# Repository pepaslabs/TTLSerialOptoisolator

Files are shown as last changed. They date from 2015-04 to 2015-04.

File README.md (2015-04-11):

# TTLSerialOptoisolator

A board which provides isolation for a TTL serial TX / RX pair.

## License

This board design is [Open-Source Hardware](http://www.oshwa.org/definition/).  It is licensed under the [MIT License](http://opensource.org/licenses/MIT).  It was designed by Jason Pepas.

# Board design v1

Initial board design.

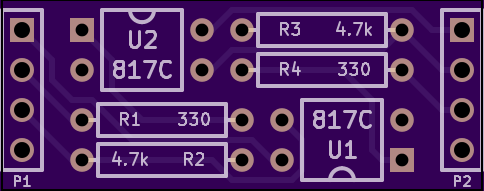
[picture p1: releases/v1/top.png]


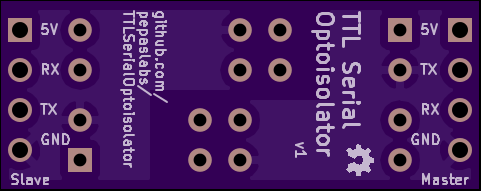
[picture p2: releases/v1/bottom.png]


## Gerbers

[gerbers.zip](releases/v1/gerbers.zip)

## Schematic

[PDF](releases/v1/TTLSerialOptoisolator%20schematic.pdf).

# Design notes

## LED series resistor calculation

Can we find an LED resistor value which works for both 3.3V and 5V TTL levels?

Lite-On LTV-817 datasheet: http://media.digikey.com/pdf/Data%20Sheets/Lite-On%20PDFs/LTV-817_827_847%28M,S,S_TA1%29.pdf

The forward voltage of the LED is typically 1.2V.

* 5V - 1.2V = 3.8V
* 3.3V - 1.2V = 2.1V

Voltage|100Ω|150Ω|220Ω|330Ω|470Ω|680Ω|1kΩ
-------|----|----|----|----|----|----|---
5V|38mA|25mA|17mA|12mA|8mA|6mA|4mA
3.3V|21mA|14mA|10mA|6mA|4mA|3mA|2mA

So 330Ω would be a reasonable choice.

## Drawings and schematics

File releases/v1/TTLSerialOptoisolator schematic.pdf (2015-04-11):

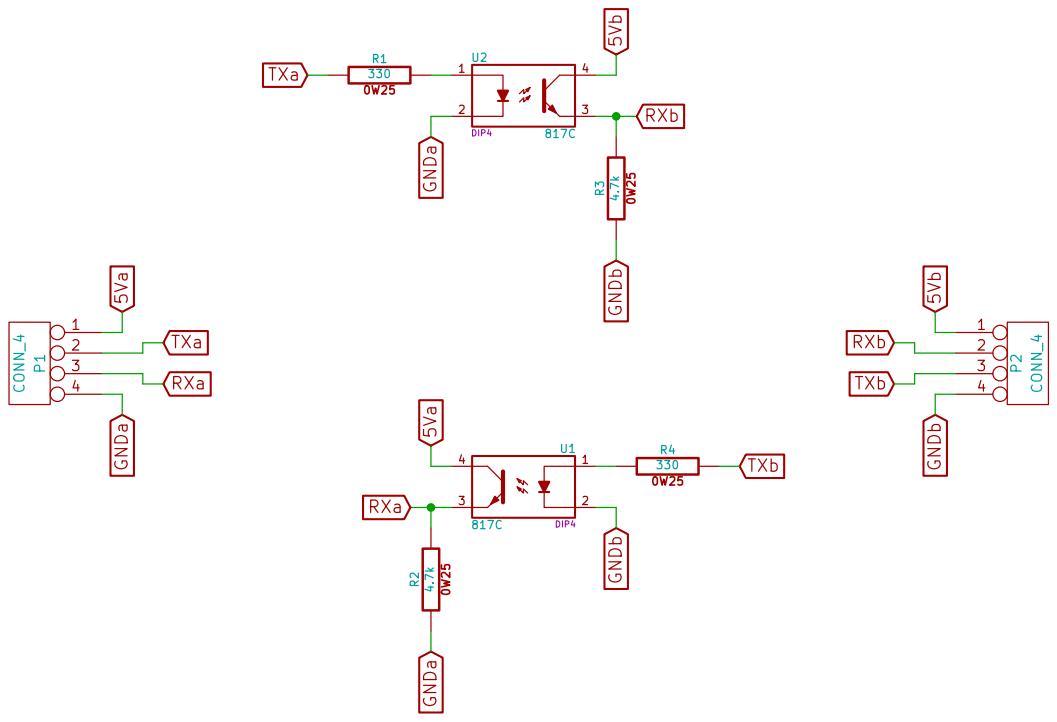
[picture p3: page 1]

Id: 1/1 Title: File: TTLSerialOptoisolator.sch

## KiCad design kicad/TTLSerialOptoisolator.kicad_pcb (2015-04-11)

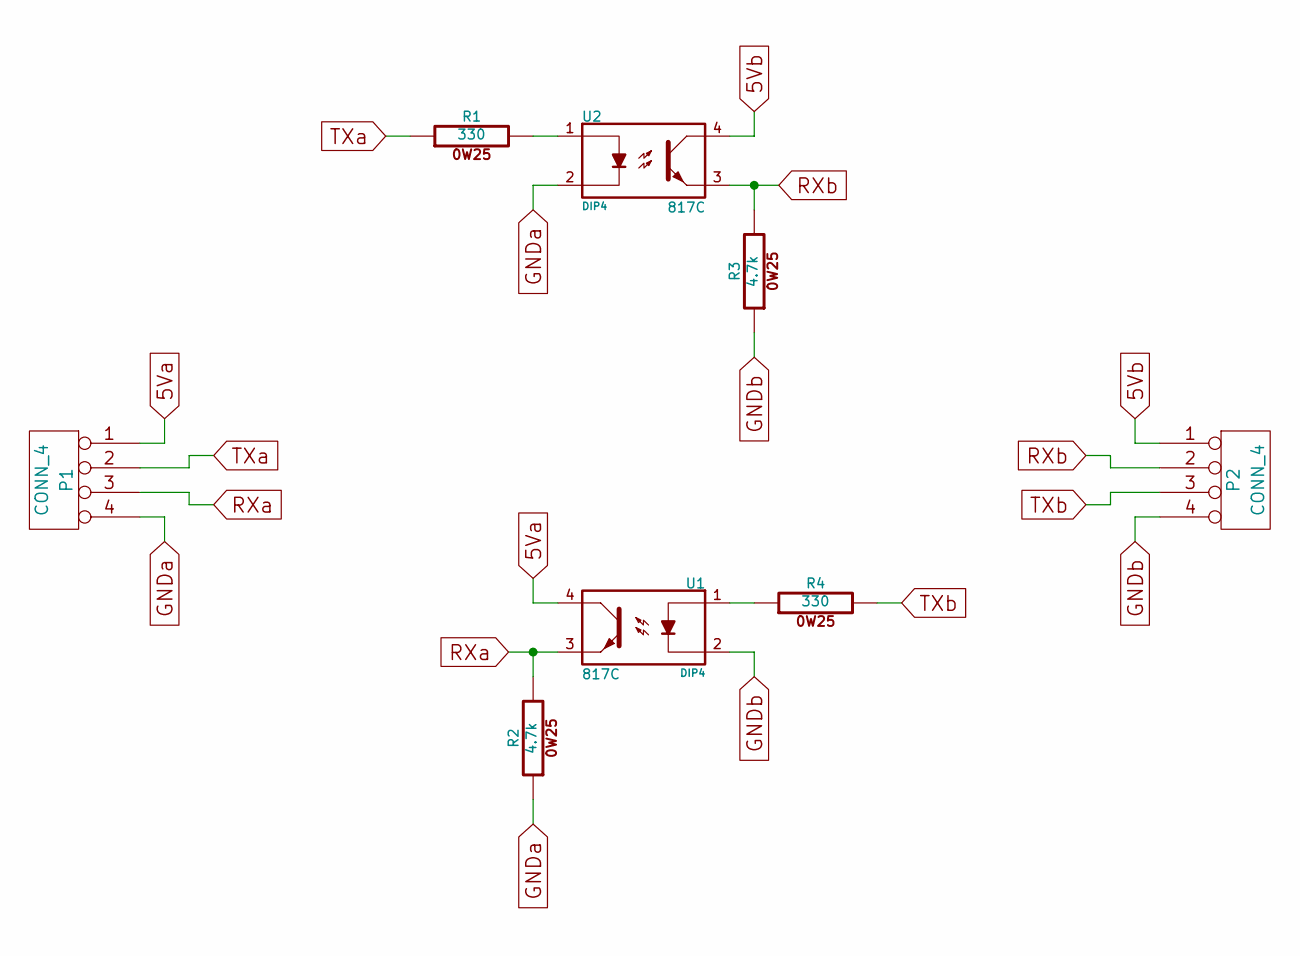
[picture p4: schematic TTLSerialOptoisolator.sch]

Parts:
P1, P2: CONN_4
R1, R4: 330
R2, R3: 4.7k
U1, U2: 817C; DIP4

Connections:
5Va: P1.1, U1.4
5Vb: P2.1, U2.4
GNDa: P1.4, R2.1, U2.2
GNDb: P2.4, R3.1, U1.2
unnamed: R4.1, U1.1
unnamed: R1.2, U2.1
RXa: P1.3, R2.2, U1.3
RXb: P2.2, R3.2, U2.3
TXa: P1.2, R1.1
TXb: P2.3, R4.2

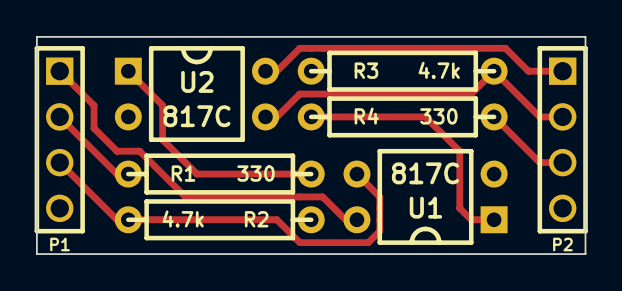
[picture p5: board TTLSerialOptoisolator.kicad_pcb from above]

Board: 2 copper layers, 30.5 x 12.1 mm, 8 parts (0 on the bottom side), 10 nets.

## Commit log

2015-04-11 creating kicad project
2015-04-11 initial opto isolator schematic
    [TTLSerialOptoisolator.kicad_pcb, TTLSerialOptoisolator.sch]
2015-04-11 initial draft of board layout
    [TTLSerialOptoisolator.sch]
2015-04-11 iterating on board layout
    [TTLSerialOptoisolator.kicad_pcb, TTLSerialOptoisolator.sch]
2015-04-11 changing LED resistor values to 330 ohm.
    [TTLSerialOptoisolator.kicad_pcb, TTLSerialOptoisolator.sch]
2015-04-11 creating gerbers for board v1.
    [TTLSerialOptoisolator-B_Cu.gbl, TTLSerialOptoisolator-B_Mask.gbs, TTLSerialOptoisolator-B_SilkS.gbo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]
2015-04-11 adding board renders
2015-04-11 adding schematic for v1 release
